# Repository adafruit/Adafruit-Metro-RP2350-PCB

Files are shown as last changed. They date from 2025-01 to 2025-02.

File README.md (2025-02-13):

## Adafruit Metro RP2350 PCB

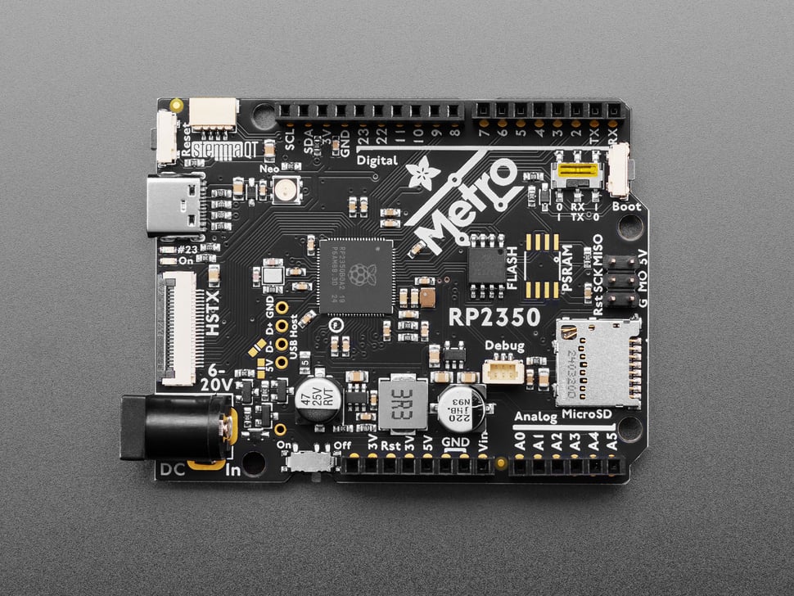
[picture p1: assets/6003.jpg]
<a href="http://www.adafruit.com/products/6003"><br/>
Click here to purchase one from the Adafruit shop</a>

PCB files for the Adafruit Metro RP2350. 

Format is EagleCAD schematic and board layout
* https://www.adafruit.com/product/6003

### Description

Choo! Choo! This is the RP2350 Metro Line, making all station stops at "Dual Cortex M33 mountain", "528K RAM round-about" and "16 Megabytes of Flash town". This train is piled high with hardware that complements the Raspberry Pi RP2350 chip to make it an excellent development board for projects that want Arduino-shape-compatibility or just need the extra space and debugging ports.

* RP2350 main chip, 150MHz clock, 3.3V logic
* 16 MB of QSPI flash for program storage
* 37 Available GPIO: 23 on the socket/SPI headers, 12 on HSTX port, and another 2 for USB host. 6 of which are also analog inputs
* Micro SD card socket wired up for SPI interfacing, also has extra pins connected for advanced-user SDIO interfacing (note that there's no code for SDIO in Arduino/Python, so this is a super-cutting-edge setup)
* 5V Buck Converter featuring TPS563201 6~17V DC input and up to 2A output
* Onboard RGB NeoPixel
* Onboard #23 LED
* Stemma QT port for I2C peripherals and sensors
* 22-pin 3-lane differential HSTX FPC port with 'Pi 5' compatible pinout, makes for quick DVI video output. Or, this also provides 12 extra GPIO that can be used for more pins.
* Reset and Boot buttons on PCB edge
* Pico Probe debug port - 3 pin JST SH compatible
* USB Type C power and data
* 5.5mm / 2.1mm DC jack for 6-17VDC power
* On/off switch for DC jack
* RX / TX switch for swapping D0 and D1 locations
* USB Host breakout pads - with controllable 5V power and D+/D- for bitbang USB Host.
* GPIO pin numbers match classic Arduino pins, other than GPIO 12 and 13 as those are needed for HSTX connectivity

You may be wondering about the RX-TX switch: we added this because traditional Arduino board start counting the GPIO for the digital pins with 0-7 and then 8-13. However, the D0/D1 pins are also traditionally the hardware UART Serial1, where D0 is Rx and D1 is Tx. On the RP2350, however, the UART pins are the other around: D0 is Tx and D1 is Rx. Thus a DPDT switch: flip one way to have the GPIO go in order of 0-7, flip the other way to have the logical locations of the hardware UART correct but now the pin order is 1, 0, 2, 3..7. Of course, it's also handy if, like us, you often swap the pins - now you don't need to require or cut/solder traces!

Inside the RP2350 is a 'permanent ROM' USB UF2 bootloader. What that means is when you want to program new firmware, you can hold down the BOOTSEL button while plugging it into USB (or pulling down the RUN/Reset pin to ground) and it will appear as a USB disk drive you can drag the firmware onto. Folks who have been using Adafruit products will find this very familiar - we use the technique on all our native-USB boards. Just note you don't double-click reset instead hold down BOOTSEL during boot to enter the bootloader!

There is great C/C++ support, unofficial (but really good) Arduino support, an official MicroPython port, and a CircuitPython port! We of course recommend CircuitPython because we think it's the easiest way to get started and it has support with most of our drivers, displays, sensors, and more, supported out of the box so you can follow along with our CircuitPython projects and tutorials.

While the RP2350 has lots of onboard RAM, it does not have built-in FLASH memory. Instead, that is provided by the external QSPI flash chip. On this board there is 16 MB, which is shared between the program it's running and any file storage used by MicroPython or CircuitPython. When using C/C++ you get the whole flash memory, if using Python you will have about 14 MB remaining for code, files, images, fonts, etc.

RP2350 Chip features:

* Dual ARM Cortex-M33 with floating point unit or Dual RISC-V @ 150MHz
* 520 kB on-chip SRAM
* 8 kB of one-time-programmable (OTP) memory.
* Support for up to 16MB of off-chip Flash memory via dedicated QSPI bus
* Support for external QSPI PSRAM
* DMA controller, 16 channel, 4 IRQ
* Fully-connected AHB crossbar
* On-chip switched-mode power supply and programmable low-dropout regulator (LDO) to generate core voltage
* Two on-chip PLLs to generate 48 MHz USB and 150MHz core clocks
* Optional boot signing with protected OTP storage
* Hardware SHA-256 accelerator
* Hardware random number generator (TRNG)
* 48 GPIO pins, 8 of which can be used as analog inputs
* Peripherals
	* 2 UARTs
	* 2 SPI controllers
	* 2 I2C controllers
	* 24 PWM channels (compared to 16 on RP2040)
	* USB 1.1 controller and PHY, with host and device support
	* 12 PIO state machines

Please note: The Adafruit Metro RP2350 comes with the A2 version of the RP2350, which is affected by the E9 erratum. This errata affects some uses of GPIO and PIO such as high-impedance inputs and the internal pulldowns. You may need to use 8.2K or smaller resistors if pull-downs are required. At this time, Feb 2025, there is no other version of the RP2350 available - only the A2 version.

### License

Adafruit invests time and resources providing this open source design, please support Adafruit and open-source hardware by purchasing products from [Adafruit](https://www.adafruit.com)!

Designed by Limor Fried/Ladyada for Adafruit Industries.

Creative Commons Attribution/Share-Alike, all text above must be included in any redistribution. 
See license.txt for additional details.

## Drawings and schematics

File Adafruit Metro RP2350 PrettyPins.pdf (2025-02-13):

# Adafruit Metro RP2350

# https://www.adafruit.com/product/6003

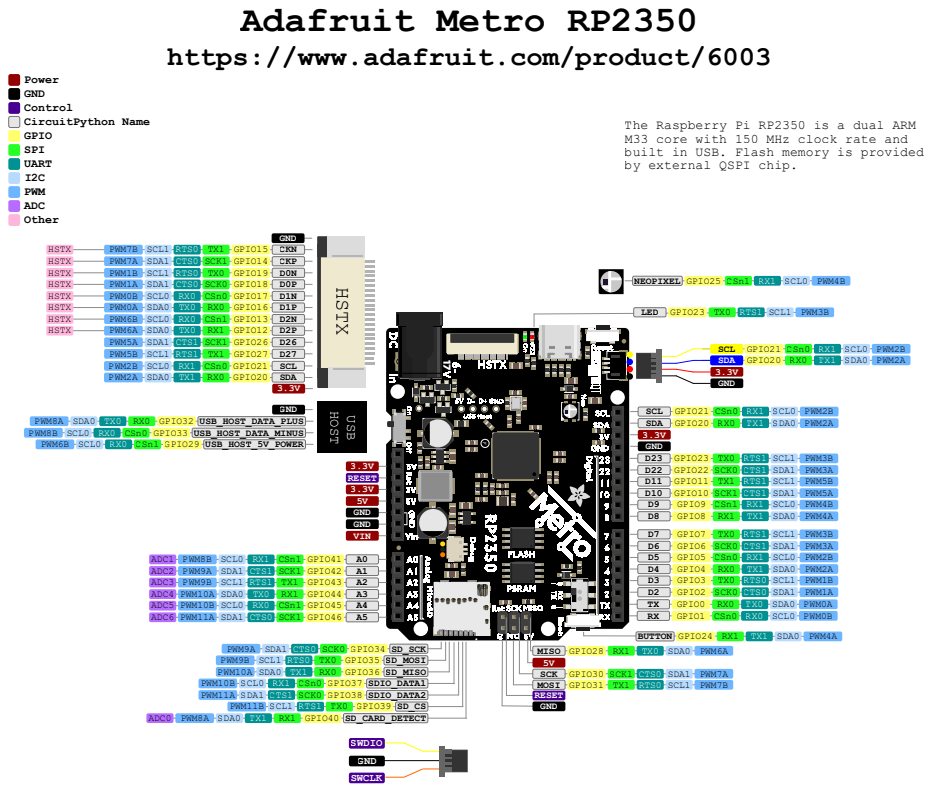
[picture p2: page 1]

The Raspberry Pi RP2350 is a dual ARM
M33 core with 150 MHz clock rate and
built in USB. Flash memory is provided
by external QSPI chip.

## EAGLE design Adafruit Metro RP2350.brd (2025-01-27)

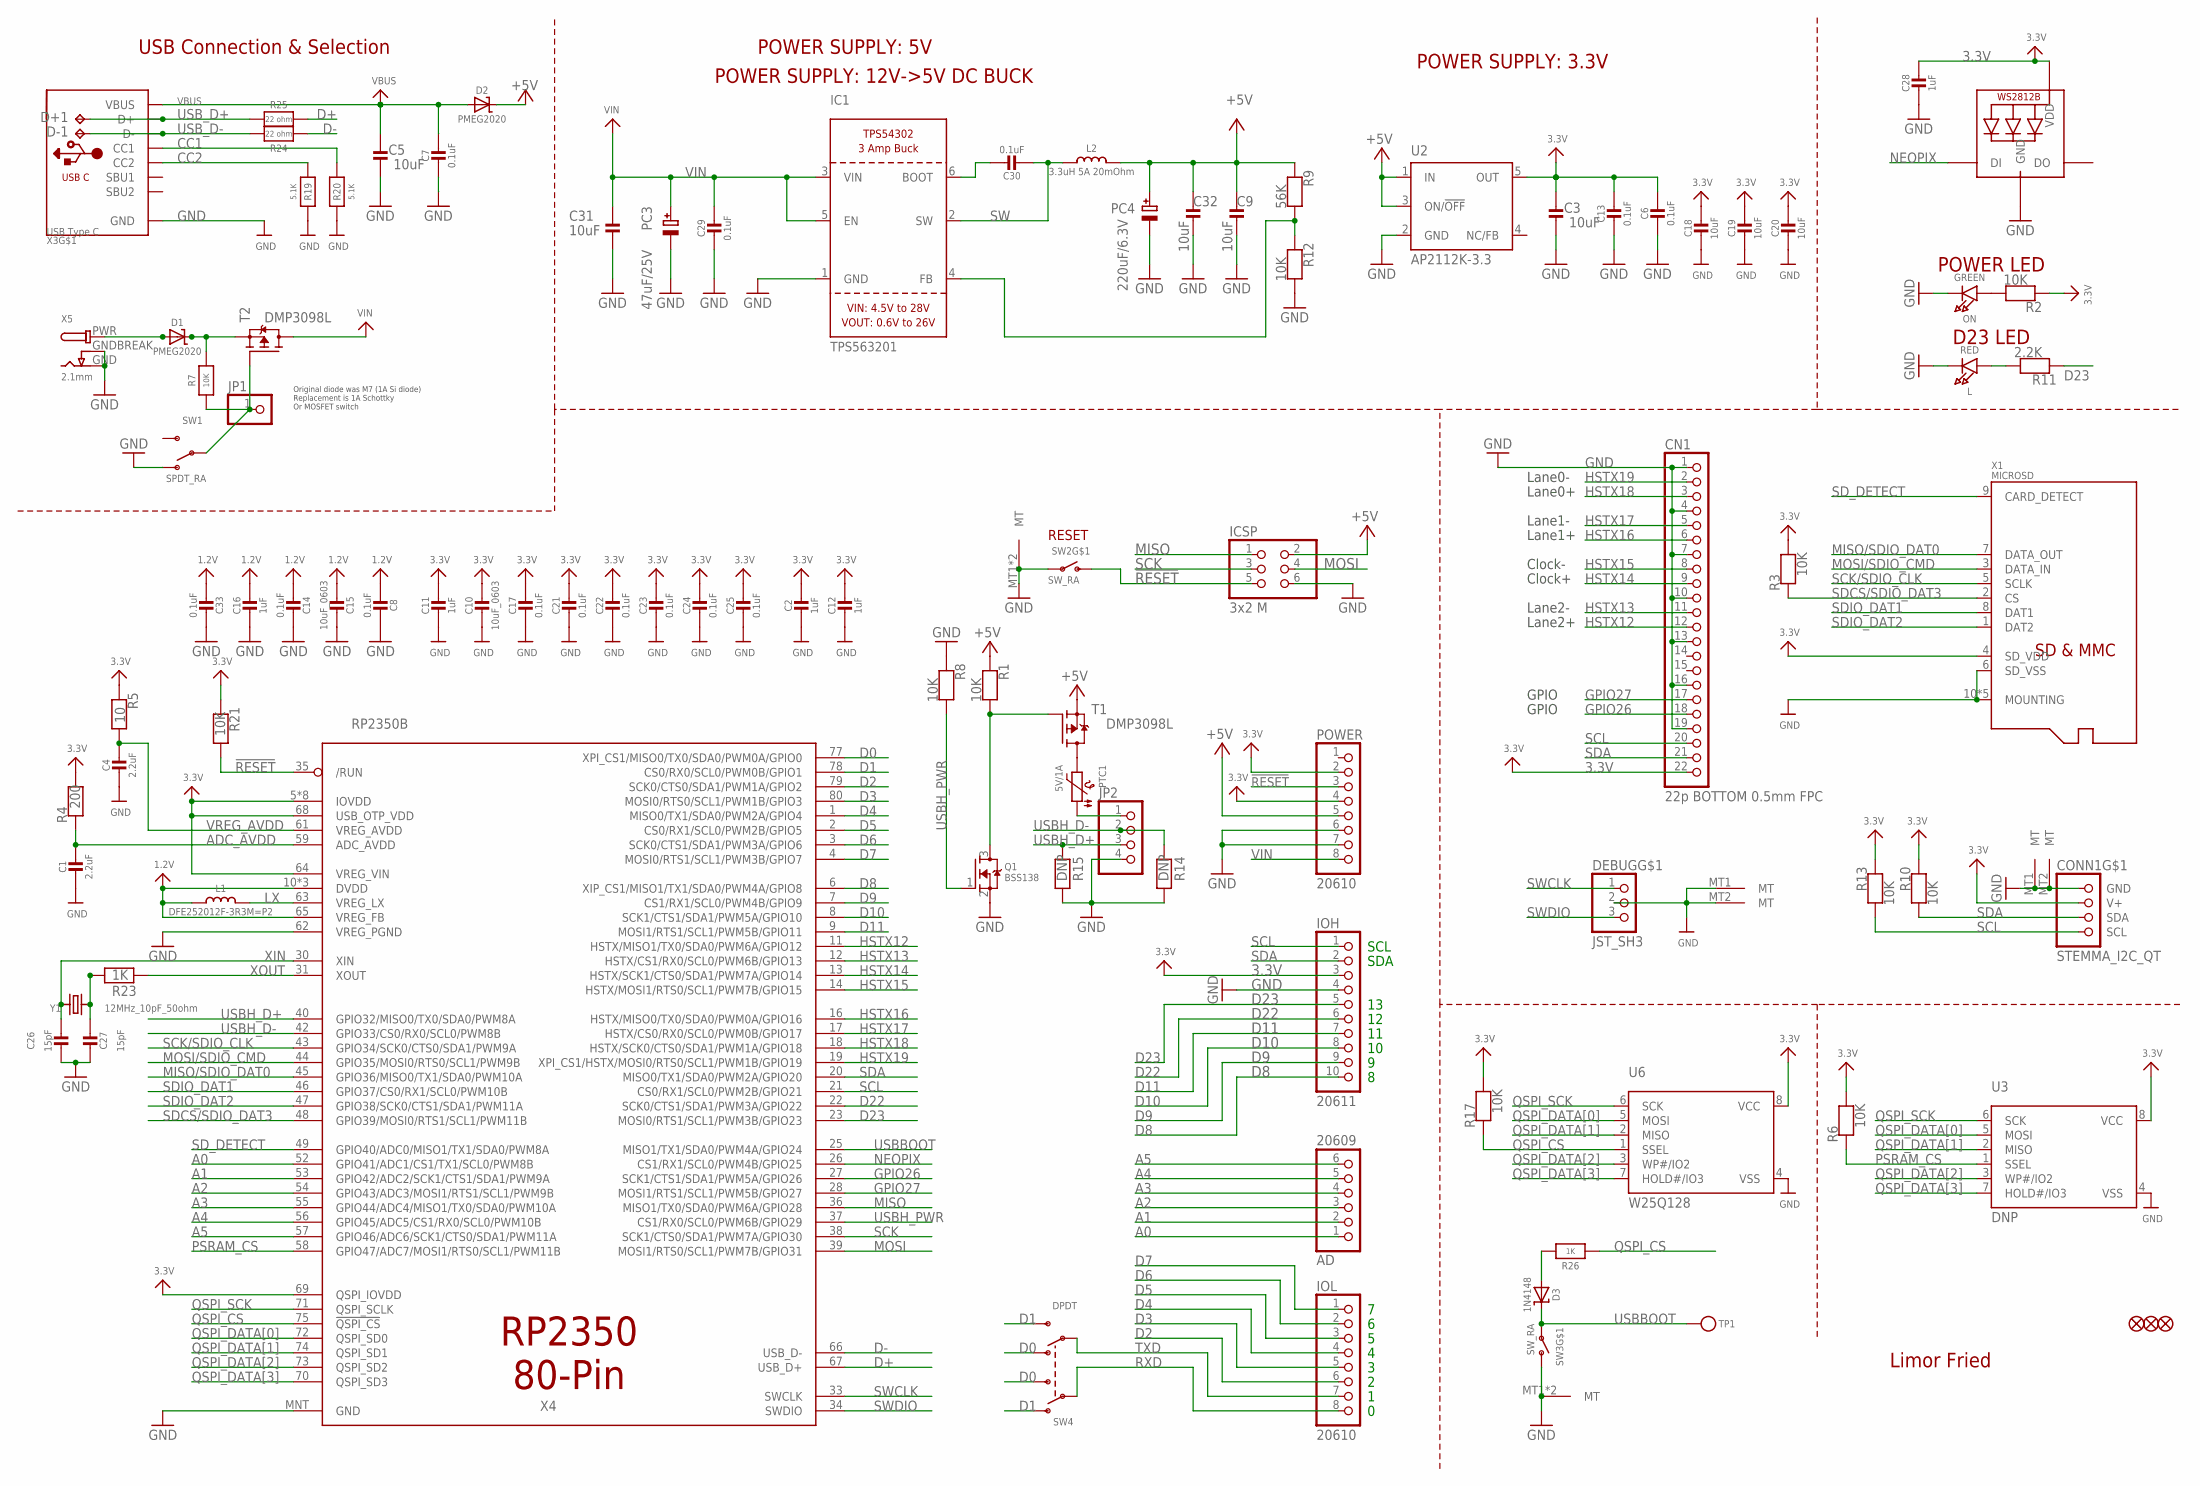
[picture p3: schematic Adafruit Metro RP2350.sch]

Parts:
AD: 20609; 1X06_OVALWAVE
C1, C4: 2.2uF; 0603-NO
C2, C11, C12, C16, C28: 1uF; 0603-NO
C3, C5, C9, C18, C19, C20, C31, C32: 10uF; 0805-NO
C6, C7, C8, C13, C14, C17, C21, C22, C23, C24, C25, C29, C30, C33: 0.1uF; 0603-NO
C10, C15: 10uF_0603; 0603-NO_WIDE
C26, C27: 15pF; 0603-NO
CN1: 22p BOTTOM 0.5mm FPC; FPC_22PIN
CONN1: STEMMA_I2C_QT; JST_SH4
D1, D2: PMEG2020; SOD-323
D3: 1N4148; SOD-323
D+1: TPB1,27; B1,27
D-1: TPB1,27; B1,27
DEBUG: JST_SH3; JST_SH3_RA
FD1, FD2, FD3: FIDUCIAL_1MM
IC1: TPS563201; SOT23-6
ICSP: 3x2 M; 2X03_ROUND_70MIL
IOH: 20611; 1X10_OVALWAVE
IOL: 20610; 1X08_OVALWAVE
JP1: HEADER-1X1ROUND; 1X01_ROUND
JP2: HEADER-1X4ROUND; 1X04_ROUND
L: RED; CHIPLED_0603_NOOUTLINE
L1: DFE252012F-3R3M=P2; INDUCTOR_1007
L2: 3.3uH 5A 20mOhm; INDUCTOR_0603S
LED2: WS2812B_3535FULL; LED3535_FULLPADS
ON: GREEN; CHIPLED_0603_NOOUTLINE
PC3: 47uF/25V; PANASONIC_D
PC4: 220uF/6.3V; PANASONIC_D
POWER: 20610; 1X08_OVALWAVE
PTC1: 5V/1A; 0805-NO
Q1: BSS138; SOT23-WIDE
R1, R2, R3, R6, R7, R8, R10, R12, R13, R17, R21: 10K; 0603-NO
R4: 200; 0603-NO
R5: 10; 0603-NO
R9: 56K; 0603-NO
R11: 2.2K; 0603-NO
R14, R15: DNP; 0603-NO
R19, R20: 5.1K; 0603-NO
R23, R26: 1K; 0603-NO
R24, R25: 22 ohm; 0603-NO
SW1: SPDT_RA; SPDT_SMT_SSSS811101
SW2, SW3: SW_RA; SPST_TACTILE_RA
SW4: DPDT; EG1390
T1, T2: DMP3098L; SOT23-WIDE
TP1: TESTPOINTROUND1.5MMNO; TESTPOINT_ROUND_1.5MM_NO
U2: AP2112K-3.3; SOT23-DBV
U3: DNP; SOIC8_208MIL
U6: W25Q128; SOIC8_208MIL
X1: MICROSD; MOLEX_104031-0811
X3: USB Type C; USB_C_CUSB31-CFM2AX-01-X
X4: RP2350B; QFN80
X5: 2.1mm; DCJACK_2MM_PTH
Y1: 12MHz_10pF_50ohm; CRYSTAL_2.5X2

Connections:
1.2V: C8.2, C14.2, C15.2, C16.1, C33.2, L1.P$1 (1), X4.10 (DVDD), X4.32 (DVDD), X4.51 (DVDD), X4.65 (VREG_FB)
3.3V: C2.1, C3.2, C6.2, C10.1, C11.1, C12.1, C13.1, C17.1, C18.1, C19.1, C20.1, C21.1, C22.1, C23.1, C24.1, C25.1, C28.1, CN1.22, CONN1.2 (V+), IOH.3, LED2.2 (VDD), POWER.2, POWER.4, R2.1, R3.2, R4.2, R5.1, R6.2, R10.1, R13.1, R17.2, R21.1, U2.5 (OUT), U3.8 (VCC), U6.8 (VCC), X1.4 (SD_VDD), X4.5 (IOVDD), X4.15 (IOVDD), X4.24 (IOVDD), X4.29 (IOVDD), X4.41 (IOVDD), X4.50 (IOVDD), X4.60 (IOVDD), X4.64 (VREG_VIN), X4.68 (USB_OTP_VDD), X4.69 (QSPI_IOVDD), X4.76 (IOVDD)
!RESET: ICSP.5, POWER.3, R21.2, SW2.2 (S), X4.35 (/RUN)
+5V: C9.2, C32.2, D2.C, ICSP.2, L2.P$2 (2), PC4.+, POWER.5, R1.1, R9.1, T1.2 (S), U2.1 (IN), U2.3 (ON/!OFF)
A0: AD.1, X4.52 (GPIO41/ADC1/CS1/TX1/SCL0/PWM8B)
A1: AD.2, X4.53 (GPIO42/ADC2/SCK1/CTS1/SDA1/PWM9A)
A2: AD.3, X4.54 (GPIO43/ADC3/MOSI1/RTS1/SCL1/PWM9B)
A3: AD.4, X4.55 (GPIO44/ADC4/MISO1/TX0/SDA0/PWM10A)
A4: AD.5, X4.56 (GPIO45/ADC5/CS1/RX0/SCL0/PWM10B)
A5: AD.6, X4.57 (GPIO46/ADC6/SCK1/CTS0/SDA1/PWM11A)
ADC_AVDD: C1.1, R4.1, X4.59 (ADC_AVDD)
CC1: R20.2, X3.A5 (CC1)
CC2: R19.2, X3.B5 (CC2)
D0: SW4.O2, SW4.S1, X4.77 (XPI_CS1/MISO0/TX0/SDA0/PWM0A/GPIO0)
D1: SW4.O1, SW4.S2, X4.78 (CS0/RX0/SCL0/PWM0B/GPIO1)
D2: IOL.6, X4.79 (SCK0/CTS0/SDA1/PWM1A/GPIO2)
D3: IOL.5, X4.80 (MOSI0/RTS0/SCL1/PWM1B/GPIO3)
D4: IOL.4, X4.1 (MISO0/TX1/SDA0/PWM2A/GPIO4)
D5: IOL.3, X4.2 (CS0/RX1/SCL0/PWM2B/GPIO5)
D6: IOL.2, X4.3 (SCK0/CTS1/SDA1/PWM3A/GPIO6)
D7: IOL.1, X4.4 (MOSI0/RTS1/SCL1/PWM3B/GPIO7)
D8: IOH.10, X4.6 (XIP_CS1/MISO1/TX1/SDA0/PWM4A/GPIO8)
D9: IOH.9, X4.7 (CS1/RX1/SCL0/PWM4B/GPIO9)
D10: IOH.8, X4.8 (SCK1/CTS1/SDA1/PWM5A/GPIO10)
D11: IOH.7, X4.9 (MOSI1/RTS1/SCL1/PWM5B/GPIO11)
D22: IOH.6, X4.22 (SCK0/CTS1/SDA1/PWM3A/GPIO22)
D23: IOH.5, R11.1, X4.23 (MOSI0/RTS1/SCL1/PWM3B/GPIO23)
D+: R25.2, X4.67 (USB_D+)
D-: R24.2, X4.66 (USB_D-)
GND: C1.2, C2.2, C3.1, C4.2, C5.1, C6.1, C7.2, C8.1, C9.1, C10.2, C11.2, C12.2, C13.2, C14.1, C15.1, C16.2, C17.2, C18.2, C19.2, C20.2, C21.2, C22.2, C23.2, C24.2, C25.2, C26.1, C27.1, C28.2, C29.2, C31.1, C32.1, C33.1, CN1.1, CN1.4, CN1.7, CN1.10, CN1.13, CN1.16, CN1.19, CONN1.1 (GND), CONN1.MT1 (MT), CONN1.MT2 (MT), DEBUG.2, DEBUG.MT1 (MT), DEBUG.MT2 (MT), IC1.1 (GND), ICSP.6, IOH.4, JP2.4, L.C, LED2.4 (GND), ON.C, PC3.-, PC4.-, POWER.6, POWER.7, Q1.2 (S), R8.1, R12.2, R14.1, R15.1, R19.1, R20.1, SW1.A (O), SW2.1, SW2.MT1 (MT), SW2.MT2 (MT), SW3.2 (S), SW3.MT1 (MT), SW3.MT2 (MT), U2.2 (GND), U3.4 (VSS), U6.4 (VSS), X1.6 (SD_VSS), X1.10 (MOUNTING), X1.G1 (MOUNTING), X1.G2 (MOUNTING), X1.G3 (MOUNTING), X1.G4 (MOUNTING), X3.A1B12 (GND), X3.B1A12 (GND), X4.62 (VREG_PGND), X4.MNT (GND), X5.GND, X5.GNDBREAK
GPIO26: CN1.18, X4.27 (SCK1/CTS1/SDA1/PWM5A/GPIO26)
GPIO27: CN1.17, X4.28 (MOSI1/RTS1/SCL1/PWM5B/GPIO27)
HSTX12: CN1.12, X4.11 (HSTX/MISO1/TX0/SDA0/PWM6A/GPIO12)
HSTX13: CN1.11, X4.12 (HSTX/CS1/RX0/SCL0/PWM6B/GPIO13)
HSTX14: CN1.9, X4.13 (HSTX/SCK1/CTS0/SDA1/PWM7A/GPIO14)
HSTX15: CN1.8, X4.14 (HSTX/MOSI1/RTS0/SCL1/PWM7B/GPIO15)
HSTX16: CN1.6, X4.16 (HSTX/MISO0/TX0/SDA0/PWM0A/GPIO16)
HSTX17: CN1.5, X4.17 (HSTX/CS0/RX0/SCL0/PWM0B/GPIO17)
HSTX18: CN1.3, X4.18 (HSTX/SCK0/CTS0/SDA1/PWM1A/GPIO18)
HSTX19: CN1.2, X4.19 (XPI_CS1/HSTX/MOSI0/RTS0/SCL1/PWM1B/GPIO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)
LX: L1.P$2 (2), X4.63 (VREG_LX)
MISO: ICSP.1, X4.36 (MISO1/TX0/SDA0/PWM6A/GPIO28)
MISO/SDIO_DAT0: X1.7 (DATA_OUT), X4.45 (GPIO36/MISO0/TX1/SDA0/PWM10A)
MOSI: ICSP.4, X4.39 (MOSI1/RTS0/SCL1/PWM7B/GPIO31)
MOSI/SDIO_CMD: X1.3 (DATA_IN), X4.44 (GPIO35/MOSI0/RTS0/SCL1/PWM9B)
unnamed: L.A, R11.2
unnamed: ON.A, R2.2
unnamed: JP2.1, PTC1.1
unnamed: PTC1.2, T1.3 (D)
unnamed: Q1.3 (D), R1.2, T1.1 (G)
unnamed: D3.A, R26.2
unnamed: C30.1, IC1.6 (BOOT)
unnamed: IC1.4 (FB), R9.2, R12.1
unnamed: C27.2, R23.1, Y1.3 (2)
unnamed: D1.C, R7.2, T2.2 (S)
NEOPIX: LED2.1 (DI), X4.26 (CS1/RX1/SCL0/PWM4B/GPIO25)
PSRAM_CS: R6.1, U3.1 (SSEL), X4.58 (GPIO47/ADC7/MOSI1/RTS0/SCL1/PWM11B)
PWRIN: D1.A, X5.PWR
PWR_SWITCH: JP1.1, R7.1, SW1.B, T2.1 (G)
QSPI_CS: R17.1, R26.1, U6.1 (SSEL), X4.75 (!QSPI_CS)
QSPI_DATA[0]: U3.5 (MOSI), U6.5 (MOSI), X4.72 (QSPI_SD0)
QSPI_DATA[1]: U3.2 (MISO), U6.2 (MISO), X4.74 (QSPI_SD1)
QSPI_DATA[2]: U3.3 (WP#/IO2), U6.3 (WP#/IO2), X4.73 (QSPI_SD2)
QSPI_DATA[3]: U3.7 (HOLD#/IO3), U6.7 (HOLD#/IO3), X4.70 (QSPI_SD3)
QSPI_SCK: U3.6 (SCK), U6.6 (SCK), X4.71 (QSPI_SCLK)
RXD: IOL.8, SW4.P1
SCK: ICSP.3, X4.38 (SCK1/CTS0/SDA1/PWM7A/GPIO30)
SCK/SDIO_CLK: X1.5 (SCLK), X4.43 (GPIO34/SCK0/CTS0/SDA1/PWM9A)
SCL: CN1.20, CONN1.4 (SCL), IOH.1, R13.2, X4.21 (CS0/RX1/SCL0/PWM2B/GPIO21)
SDA: CN1.21, CONN1.3 (SDA), IOH.2, R10.2, X4.20 (MISO0/TX1/SDA0/PWM2A/GPIO20)
SDCS/SDIO_DAT3: R3.1, X1.2 (CS), X4.48 (GPIO39/MOSI0/RTS1/SCL1/PWM11B)
SDIO_DAT1: X1.8 (DAT1), X4.46 (GPIO37/CS0/RX1/SCL0/PWM10B)
SDIO_DAT2: X1.1 (DAT2), X4.47 (GPIO38/SCK0/CTS1/SDA1/PWM11A)
SD_DETECT: X1.9 (CARD_DETECT), X4.49 (GPIO40/ADC0/MISO1/TX1/SDA0/PWM8A)
SW: C30.2, IC1.2 (SW), L2.P$1 (1)
SWCLK: DEBUG.1, X4.33 (SWCLK)
SWDIO: DEBUG.3, X4.34 (SWDIO)
TXD: IOL.7, SW4.P2
USBBOOT: D3.C, SW3.1, TP1.P$1, X4.25 (MISO1/TX1/SDA0/PWM4A/GPIO24)
USBH_D+: JP2.3, R15.2, X4.40 (GPIO32/MISO0/TX0/SDA0/PWM8A)
USBH_D-: JP2.2, R14.2, X4.42 (GPIO33/CS0/RX0/SCL0/PWM8B)
USBH_PWR: Q1.1 (G), R8.2, X4.37 (CS1/RX0/SCL0/PWM6B/GPIO29)
USB_D+: D+1.TP, R25.1, X3.A6 (D+), X3.B6 (D+)
USB_D-: D-1.TP, R24.1, X3.A7 (D-), X3.B7 (D-)
VBUS: C5.2, C7.1, D2.A, X3.A4B9 (VBUS), X3.B4A9 (VBUS)
VIN: C29.1, C31.2, IC1.3 (VIN), IC1.5 (EN), PC3.+, POWER.8, T2.3 (D)
VREG_AVDD: C4.1, R5.2, X4.61 (VREG_AVDD)
XIN: C26.2, X4.30 (XIN), Y1.1
XOUT: R23.2, X4.31 (XOUT)

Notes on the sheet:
SDA
SCL
Limor Fried
Original diode was M7 (1A Si diode) Replacement is 1A Schottky Or MOSFET switch
POWER SUPPLY: 5V
USB Connection & Selection
POWER SUPPLY: 3.3V
POWER LED
D23 LED
RESET
Lane0-
Lane0+
Lane1-
Lane1+
Clock-
Clock+
Lane2-
Lane2+
GPIO
POWER SUPPLY: 12V->5V DC BUCK

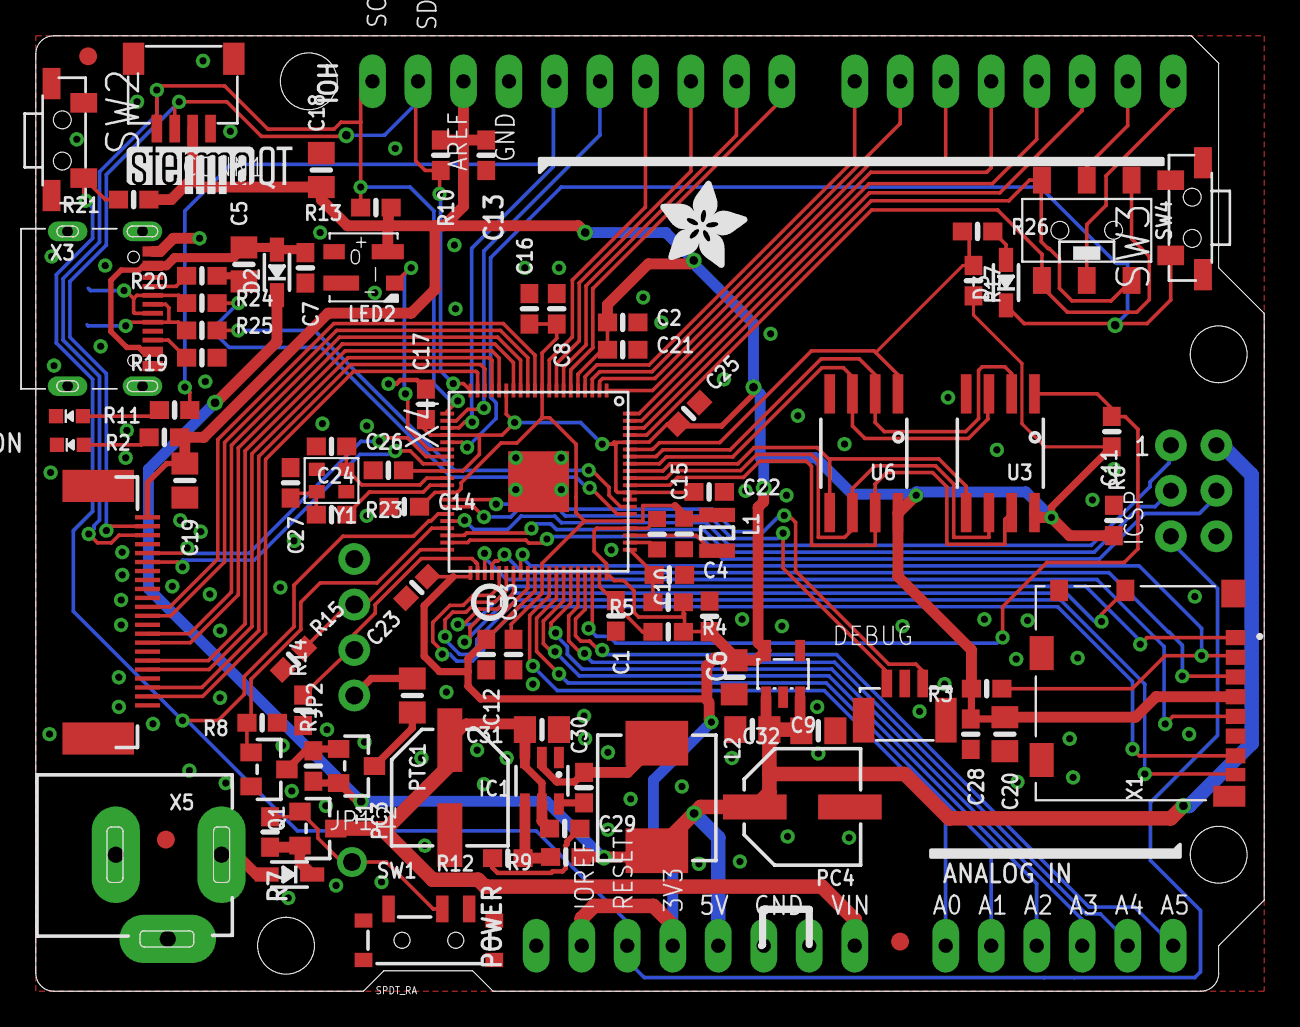
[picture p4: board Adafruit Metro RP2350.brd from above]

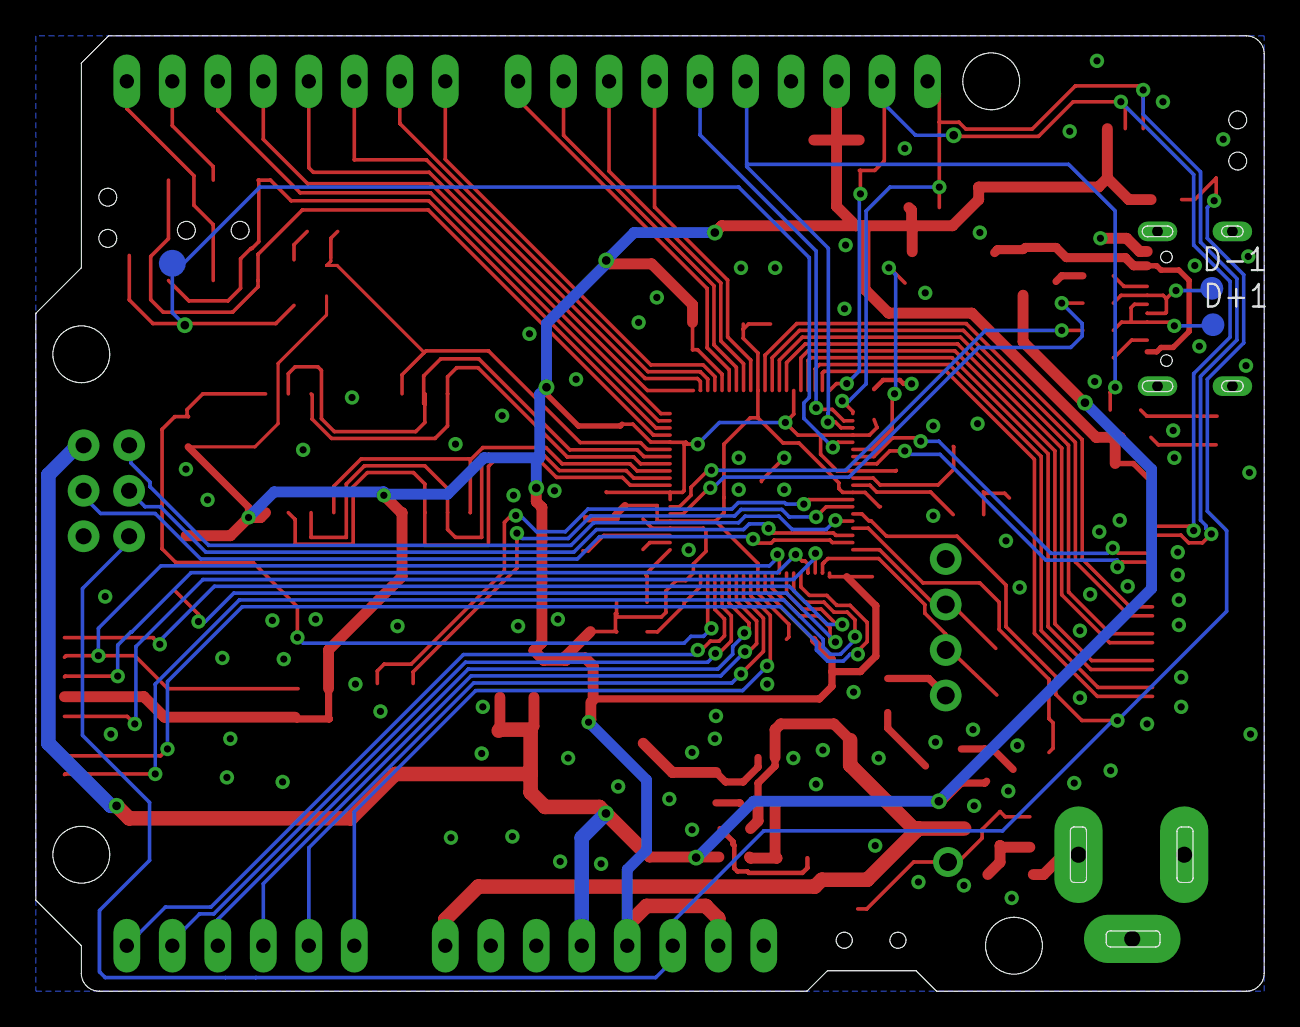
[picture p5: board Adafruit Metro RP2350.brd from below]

Board: 2 copper layers, 68.6 x 53.3 mm, 170 parts (5 on the bottom side), 89 nets.

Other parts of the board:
PLABEL0: PLABEL0
PLABEL1: PLABEL1
PLABEL2: PLABEL2
PLABEL3: PLABEL3
PLABEL4: PLABEL4
PLABEL5: PLABEL5
PLABEL6: PLABEL6
PLABEL7: PLABEL7
PLABEL8: PLABEL8
PLABEL10: PLABEL10
PLABEL11: PLABEL11
PLABEL12: PLABEL12
PLABEL13: PLABEL13
PLABEL14: PLABEL14
PLABEL15: PLABEL15
PLABEL16: PLABEL16
PLABEL17: PLABEL17
PLABEL18: PLABEL18
PLABEL19: PLABEL19
PLABEL20: PLABEL20
PLABEL21: PLABEL21
PLABEL22: PLABEL22
PLABEL23: PLABEL23
PLABEL24: PLABEL24
PLABEL25: PLABEL25
PLABEL26: PLABEL26
PLABEL27: PLABEL27
PLABEL28: PLABEL28
PLABEL29: PLABEL29
PLABEL30: PLABEL30
PLABEL31: PLABEL31
PLABEL32: PLABEL32
PLABEL33: PLABEL33
PLABEL34: PLABEL34
PLABEL35: PLABEL35
PLABEL36: PLABEL36
PLABEL37: PLABEL37
PLABEL38: PLABEL38
PLABEL39: PLABEL39
PLABEL40: PLABEL40
PLABEL41: PLABEL41
PLABEL42: PLABEL42
PLABEL43: PLABEL43
PLABEL46: PLABEL46
PLABEL47: PLABEL47
PLABEL48: PLABEL48
PLABEL49: PLABEL49
PLABEL50: PLABEL50
PLABEL51: PLABEL51
PLABEL52: PLABEL52
PLABEL53: PLABEL53
PLABEL54: PLABEL54
PLABEL55: PLABEL55
PLABEL56: PLABEL56
PLABEL57: PLABEL57
PLABEL59: PLABEL59
PLABEL60: PLABEL60
PLABEL62: PLABEL62
PLABEL63: PLABEL63
PLABEL64: PLABEL64
PLABEL65: PLABEL65
PLABEL66: PLABEL66
PLABEL67: PLABEL67
PLABEL68: PLABEL68
PLABEL69: PLABEL69
PLABEL70: PLABEL70
U$3: STEMMAQT
U$11: PCBFEAT-REV-040
U$47: METRO_RP2350_TOP
U$50: ADAFRUIT_5MM
U$71: METRO_RP2350_BOT

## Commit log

2024-12-18 eagle files
    [Adafruit Metro RP2350.brd, Adafruit Metro RP2350.sch]
2025-01-27 final board silk
    [Adafruit Metro RP2350.brd]

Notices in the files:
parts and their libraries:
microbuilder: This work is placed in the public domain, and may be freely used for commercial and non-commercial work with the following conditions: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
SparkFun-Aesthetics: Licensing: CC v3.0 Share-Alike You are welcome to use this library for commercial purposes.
